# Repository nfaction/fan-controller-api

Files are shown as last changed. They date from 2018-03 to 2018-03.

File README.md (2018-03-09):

# fan-controller-api

API Endpoint for Fan Remote Controller

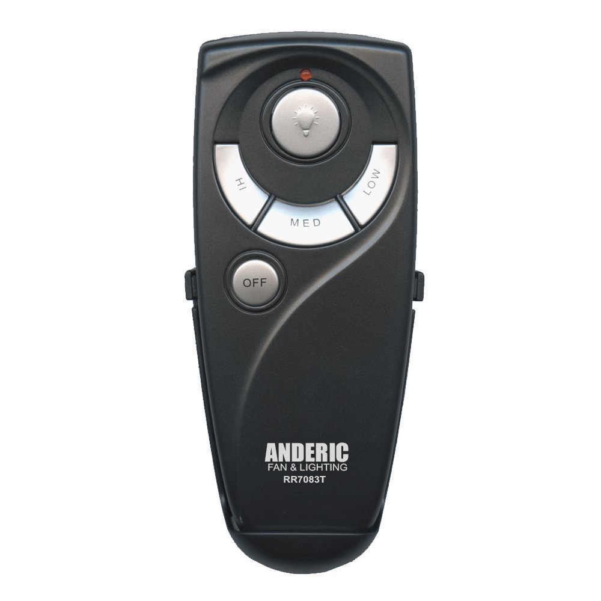
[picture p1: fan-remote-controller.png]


## Parts

* ($5.99) PCB Mount Screw Terminal Blocks: <http://a.co/jd3RjUB>
* ($7.89) Optocoupler PC817C DIP-4: <http://a.co/bq2HAgH>
* ($19.95) Hampton Bay UC7083T Ceiling Fan Remote Control: <http://a.co/2tVAojX>
* ($3.50)  WEMOS D1 mini (ESP8266) Choose one:
	* v3.0.0 ($3.50): [aliexpress wemos](https://www.aliexpress.com/store/product/D1-mini-Mini-NodeMcu-4M-bytes-Lua-WIFI-Internet-of-Things-development-board-based-ESP8266/1331105_32529101036.html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)
	* v1 ($2.69) [aliexpress wemos](https://www.aliexpress.com/item/ESP8266-ESP12-ESP-12-WeMos-D1-Mini-WIFI-Dev-Kit-Development-Board-NodeMCU-Lua/32653918483.html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,searchweb201602_1_10152_10151_10065_10344_10130_10068_10324_10342_10547_10325_10343_10546_10340_10548_10341_10545_10084_10083_10618_10630_10307_10313_10059_10534_100031_10103_10627_10626_10624_10623_10622_10621_10620_10142,searchweb201603_25,ppcSwitch_5&algo_expid=4779d5af-12ca-44c9-bd20-c7c6f4e0208d-0&algo_pvid=4779d5af-12ca-44c9-bd20-c7c6f4e0208d&transAbTest=ae803_5&priceBeautifyAB=0)

Total: $37.33 + cost of wiring/breadboards, etc.

## Arduino/ESP8266 WeMos

### Required Libraries

* aREST: <https://github.com/marcoschwartz/aREST>
* ESP8266: <https://github.com/esp8266/Arduino>

## Circuit Diagram

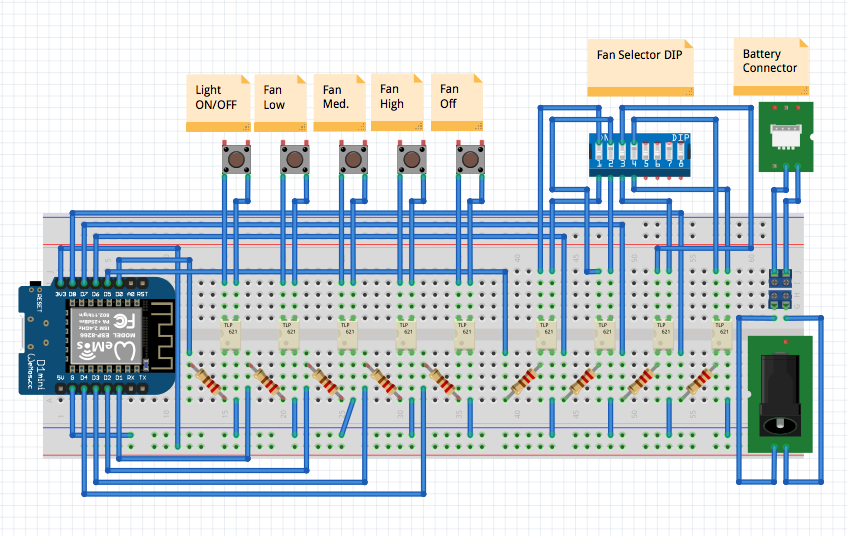
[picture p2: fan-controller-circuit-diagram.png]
WeMos Fan Controller


## API

```
$ curl http://<wemos-ip>/livingroom?params=0 | python -m json.tool
{
    "connected": true,
    "hardware": "esp8266",
    "id": "6",
    "name": "hbfans",
    "return_value": 1
}
```

## Resources

* WeMos D1R2 Pinout: <https://wiki.wemos.cc/products:d1:d1>
* Optocoupler Spec. sheet: <http://www.learningaboutelectronics.com/Articles/Optocoupler-circuit.php>

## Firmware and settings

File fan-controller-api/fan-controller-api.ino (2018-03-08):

// Import required libraries
#include <ESP8266WiFi.h>
#include <aREST.h>

// Create aREST instance
aREST rest = aREST();

// WiFi parameters
const char* ssid     = "<ssid>";
const char* password = "<ssid-passphrase>";

// The port to listen for incoming TCP connections
#define LISTEN_PORT           80

// Create an instance of the server
WiFiServer server(LISTEN_PORT);

// Light
const int light = 16;
// Fan Low
const int low = 5;
// Fan Medium
const int med = 4;
// Fan High
const int high = 0;
// Fan Off
const int foff = 2;

// Remote DIP Switches
const int f4 = 14;
const int f3 = 12;
const int f2 = 13;
const int f1 = 15;

// Button Press Time
const int buttonTime = 300;

void setup() {
  // Baud rate
  Serial.begin(115200);
  delay(100);

  // Set outputs to be used for Fan and light controls
  pinMode(light, OUTPUT);
  digitalWrite(light, LOW);
  pinMode(low, OUTPUT);
  digitalWrite(low, LOW);
  pinMode(med, OUTPUT);
  digitalWrite(med, LOW);
  pinMode(high, OUTPUT);
  digitalWrite(high, LOW);

  pinMode(foff, OUTPUT);
  digitalWrite(foff, LOW);
  
  // Fan Selectors
  pinMode(f4, OUTPUT);
  digitalWrite(f4, LOW);
  pinMode(f3, OUTPUT);
  digitalWrite(f3, LOW);
  pinMode(f2, OUTPUT);
  digitalWrite(f2, LOW);
  pinMode(f1, OUTPUT);
  digitalWrite(f1, LOW);
  delay(300);      

  // Function to be exposed
  rest.function("office",office);
  rest.function("livingroom",livingRoom);
  rest.function("familyroom",familyRoom);
  rest.function("masterbedroom",masterBedroom);
  rest.function("guestbedroom",guestBedroom);
  rest.function("sparebedroom",spareBedroom);

  // Give name & ID to the device (ID should be 6 characters long)
  rest.set_id("6");
  rest.set_name("hbfans");

  // Connect to WiFi
  WiFi.begin(ssid, password);
  while (WiFi.status() != WL_CONNECTED) {
    delay(500);
    Serial.print(".");
  }
  Serial.println("");
  Serial.println("WiFi connected");

  // Start the server
  server.begin();
  Serial.println("Server started");

  // Print the IP address
  Serial.println(WiFi.localIP());

  Serial.print("Board Initialized and Reset.\n");
    
}

// Main Program
void loop() {
  // Handle REST calls
  WiFiClient client = server.available();
  if (!client) {
    return;
  }
  while(!client.available()){
    delay(1);
  }
  rest.handle(client);
}


// Custom function accessible by the API
int fanOption(String command) {

  // Get state from command
  int state = command.toInt();
  Serial.println(state);
  if (state == 0) {
    digitalWrite(light, HIGH);
    delay(buttonTime);
    digitalWrite(light, LOW);
  }
  if (state == 1) {
    digitalWrite(low, HIGH);
    delay(buttonTime);
    digitalWrite(low, LOW);
  }
  if (state == 2) {
    digitalWrite(med, HIGH);
    delay(buttonTime);
    digitalWrite(med, LOW);
  }
  if (state == 3) {
    digitalWrite(high, HIGH);
    delay(buttonTime);
    digitalWrite(high, LOW);
  }
  if (state == 4) {
    digitalWrite(foff, HIGH);
    delay(buttonTime);
    digitalWrite(foff, LOW);
  }
  return state;
}

int office(String command){
  // Fan Selectors
  digitalWrite(f4, LOW);
  digitalWrite(f3, LOW);
  digitalWrite(f2, LOW);
  digitalWrite(f1, HIGH);

  delay(buttonTime);
  fanOption(command);
  delay(buttonTime);

  digitalWrite(f1, LOW);
  delay(buttonTime);
  return 1;
}

int livingRoom(String command){
  // Fan Selectors
  digitalWrite(f4, LOW);
  digitalWrite(f3, LOW);
  digitalWrite(f2, HIGH);
  digitalWrite(f1, LOW);

  delay(buttonTime);
  fanOption(command);
  delay(buttonTime);

  digitalWrite(f2, LOW);
  delay(buttonTime);
  return 1;
}

int familyRoom(String command){
  // Fan Selectors
  digitalWrite(f4, LOW);
  digitalWrite(f3, HIGH);
  digitalWrite(f2, LOW);
  digitalWrite(f1, LOW);

  delay(buttonTime);
  fanOption(command);
  delay(buttonTime);

  digitalWrite(f3, LOW);
  delay(buttonTime);
  return 1;
}

int masterBedroom(String command){
  // Fan Selectors
  digitalWrite(f4, LOW);
  digitalWrite(f3, LOW);
  digitalWrite(f2, HIGH);
  digitalWrite(f1, HIGH);

  delay(buttonTime);
  fanOption(command);
  delay(buttonTime);

  digitalWrite(f2, LOW);
  digitalWrite(f1, LOW);
  delay(buttonTime);
  return 1;
}

int guestBedroom(String command){
  // Fan Selectors
  digitalWrite(f4, LOW);
  digitalWrite(f3, HIGH);
  digitalWrite(f2, LOW);
  digitalWrite(f1, HIGH);

  delay(buttonTime);
  fanOption(command);
  delay(buttonTime);

  digitalWrite(f3, LOW);
  digitalWrite(f1, LOW);
  delay(buttonTime);
  return 1;
}

int spareBedroom(String command){
  // Fan Selectors
  digitalWrite(f4, LOW);
  digitalWrite(f3, HIGH);
  digitalWrite(f2, HIGH);
  digitalWrite(f1, LOW);

  delay(buttonTime);
  fanOption(command);
  delay(buttonTime);

  digitalWrite(f3, LOW);
  digitalWrite(f2, LOW);
  delay(buttonTime);
  return 1;
}

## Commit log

2018-03-08 Add inital code and README modified: README.md new file: fan-controller-api/fan-controller-api.ino new file: fan-controller-api/fan-controller-circuit.fzz
    [fan-controller-circuit.fzz]
2018-03-09 Add updated circuit diagram and costs modified: README.md modified: fan-controller-api/fan-controller-circuit.fzz new file: fan-controller-circuit-diagram.png new file: fan-remote-controller.png
    [fan-controller-circuit.fzz]
